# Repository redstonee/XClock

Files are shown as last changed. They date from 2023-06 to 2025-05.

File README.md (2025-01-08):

# XClock
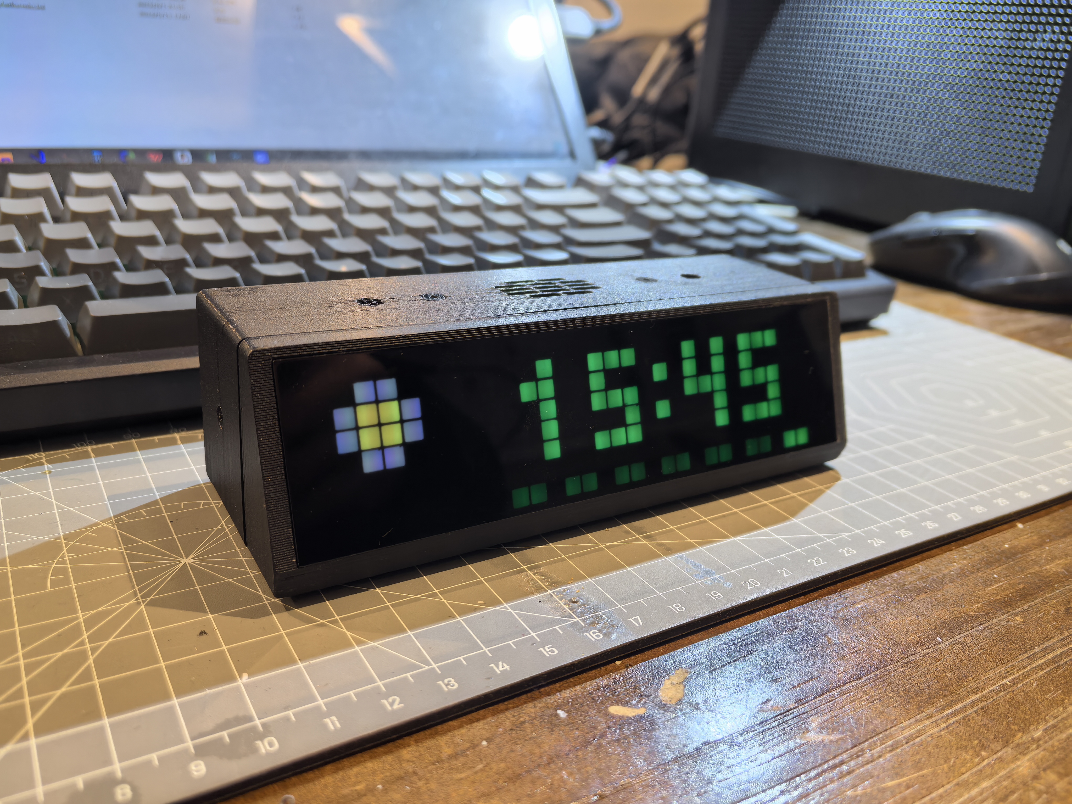
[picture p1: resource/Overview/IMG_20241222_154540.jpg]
Overview

PCB Main Board1
PCB Main Board2
PCB Display Board1
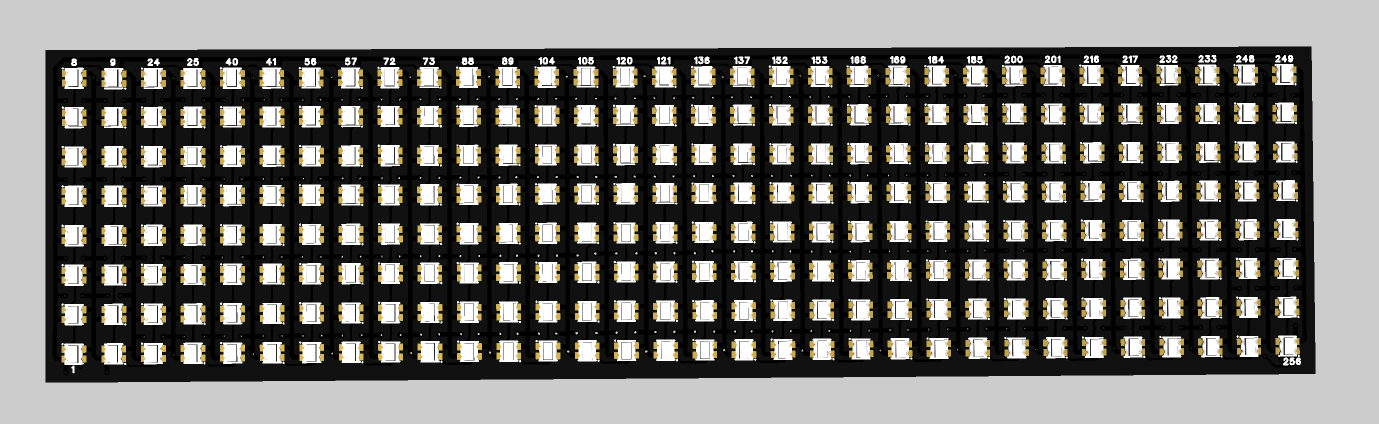
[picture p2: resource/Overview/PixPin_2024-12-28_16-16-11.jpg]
PCB Display Board2

## Background
目前网上有很多开源的点阵时钟项目，很多厉害的功能，比如可以通过小程序控制。但是大多在实用性上差那么点意思，在我的使用中最重要的一点就是需要电池供电可移动使用，我主要给我儿子写作业或者早上当闹钟使用。并且网上很多项目成品太过巨大，不够小巧。于是我萌生了自己制作一个的想法。我对点阵时钟一直有种莫名的喜爱，刚大学毕业时就打算做一个，那是还没发现有ws2812这种可以串行控制的led，现在各种硬件方案很丰富，这个项目我使用ESP32作为主控，ws2812—2020作为灯珠，能够实现非常多的功能。

## Features
* 时钟，日历，可联网显示天气
* 闹钟，可设置多个
* 秒表
* 计时器
* 音乐律动
* 显示电池电量
* 可根据环境音睡眠唤醒显示
* 可根据环境亮度自动调节显示亮度

## Usage
此时钟有3个操作按键（另外两个小按键为刷写按键），分别为左键，确认键，右键。左右键默认状态下可以切换功能，确认键可以进入每个功能的设置状态，进入设置状态之后，左右键就变为当前功能设置按键有些功能支持左右键长按操作，比如时间的加减键，功能设置状态下双击确认键可以退出设置状态。

## Hardware
硬件开源地址
[立创开源广场-XClock](https://oshwhub.com/polestar_xsx/matrixclock)

## Software
* Develop tool: VS Code + PlatformIO(vs code Extension)
* Toolchain Install：  
  1.Install VS Code  
  2.Install VS Code extension PlatformIO
  3.Git Clone soruce code  
  4.Run PlatformIO:build verify the toolchain
* 软件开发框架基于PlatformIO espressif32 arduino， PlatformIO工程中选择的开发板是esp32doit-devkit-v1。
* 使用的UI库是B站up主：创客尹白猿 开源的Dot2D库，在此表示感谢！
* 代码中使用的图片和声音资源都在resource目录下面
* 所有图片声音资源都是通过Winhex软件导出成C数组编译进ROM
* 软件支持两种图片格式：BMP，GIF。BMP用于静态图片显示，GIF用于实现动画效果。
* GIF图片使用[Pixilart](https://www.pixilart.com/ )网站编辑像素图片，导出后使用Ulead GIF Animator 5软件制作gif文件
* 声音文件使用WAV格式

## Assembly
* 外壳文件有三个，使用FreeCAD软件绘制，使用3D打印，已导出stl文件，所有文件在<resource\3DFiles\外壳>下  
  内腔.stl 前面板.stl 后壳1.stl
* 外壳使用m2x5x5平头螺丝以及配套M2x4注塑热熔铜螺母固定
* 所有连接线都是自己压线制作，连接头是2.0尺寸，当然也可以选择直接焊接不使用接插件连接
* 内置电池为两节18650，18650使用淘宝购买弹片正极端作为电极连接
* 面板淘宝定制的2mm灰色透明亚克力，尺寸38x146。亚克力后面放了一块导光膜，可以用白纸代替但是效果没那么好。
* 原理图中没有3个元件：喇叭(立创商城商品编号C969973)，光敏电阻(小于5mm)，麦克风咪头(直径9.7mm)。可根据外壳尺寸自行采购
  组装图1

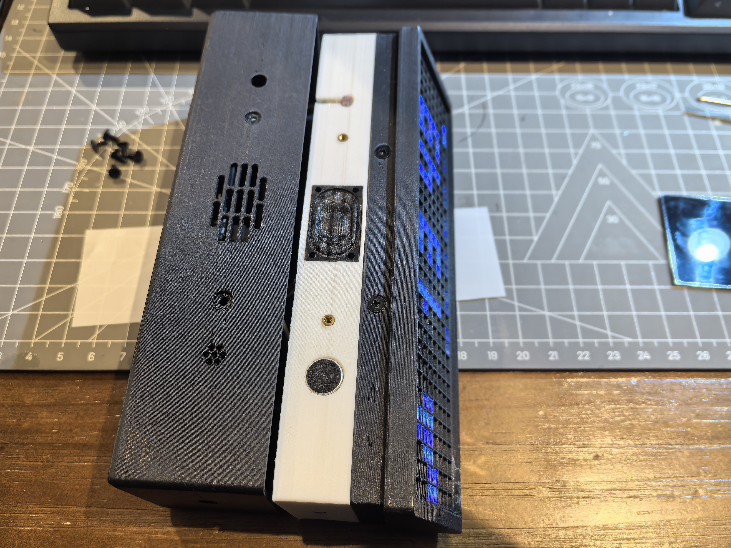
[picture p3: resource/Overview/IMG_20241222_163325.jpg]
  

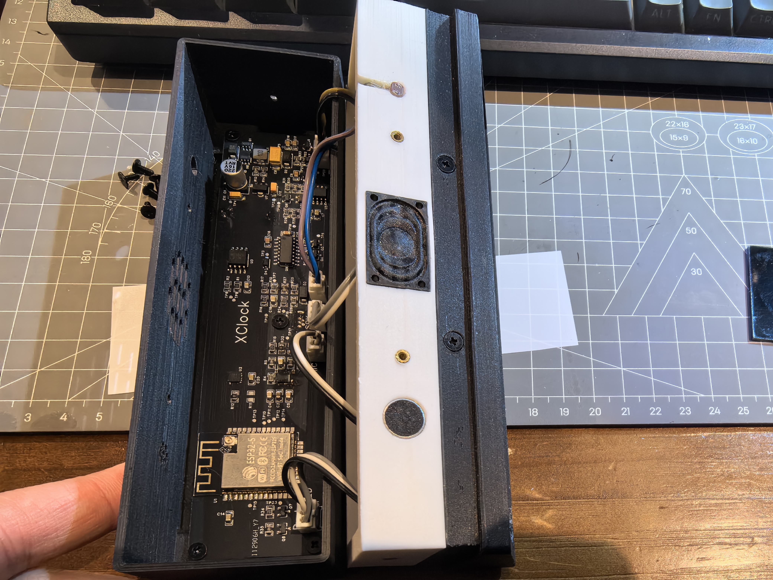
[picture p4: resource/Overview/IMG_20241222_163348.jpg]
  

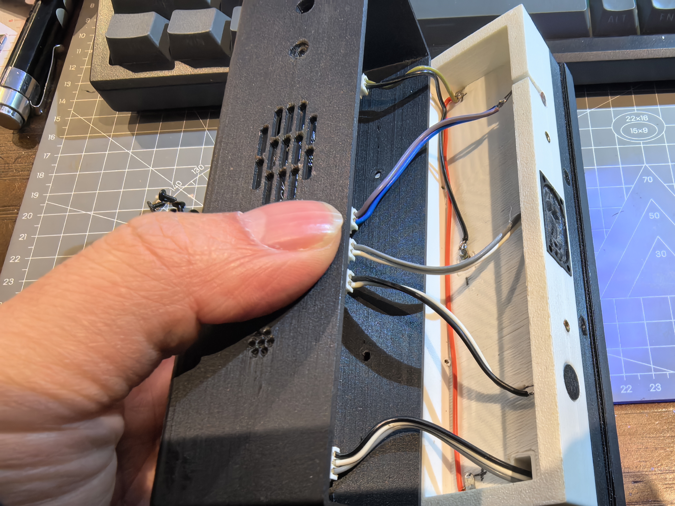
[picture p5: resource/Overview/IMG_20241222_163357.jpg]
  

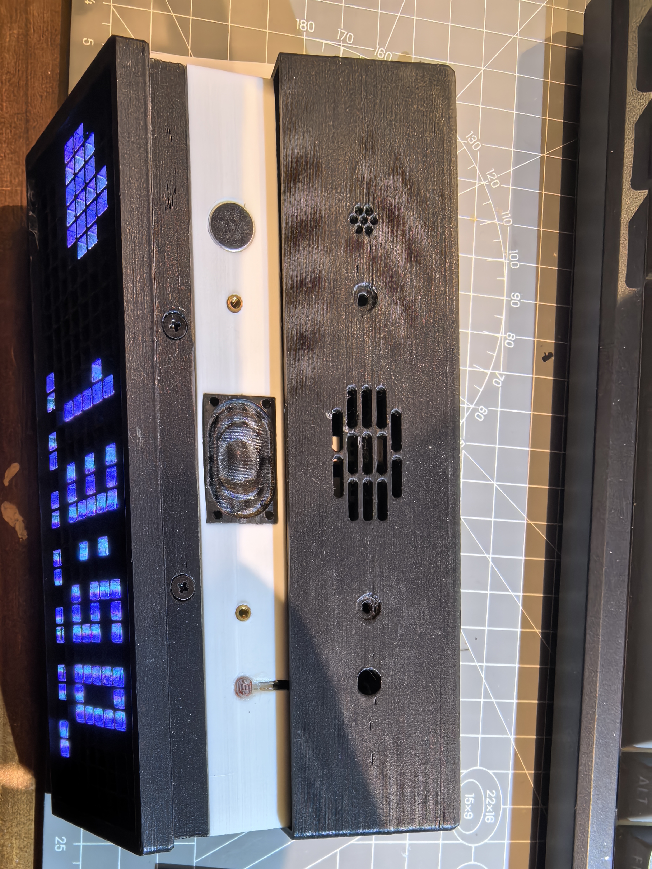
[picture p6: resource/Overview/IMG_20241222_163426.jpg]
  

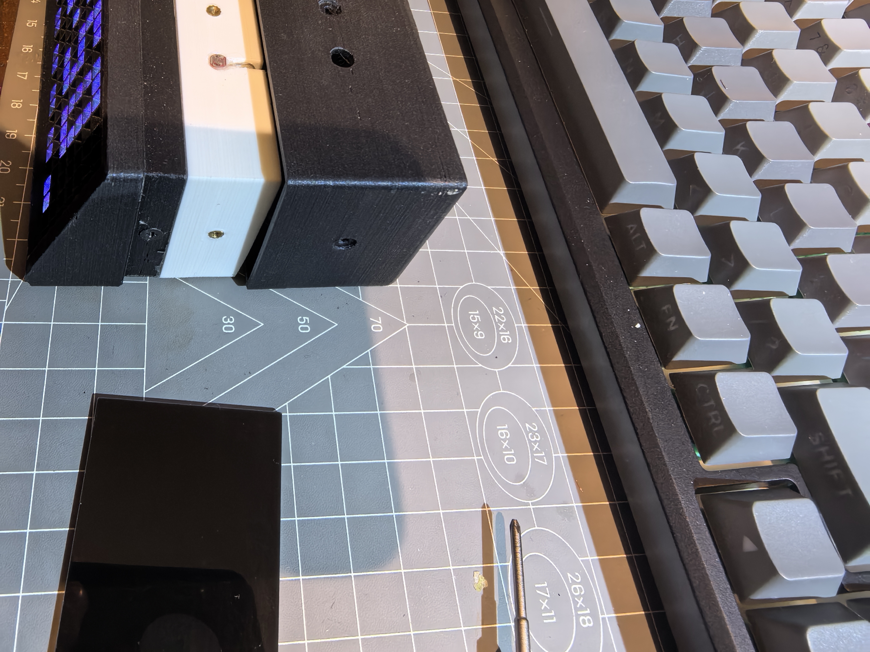
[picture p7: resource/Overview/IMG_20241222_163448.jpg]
  

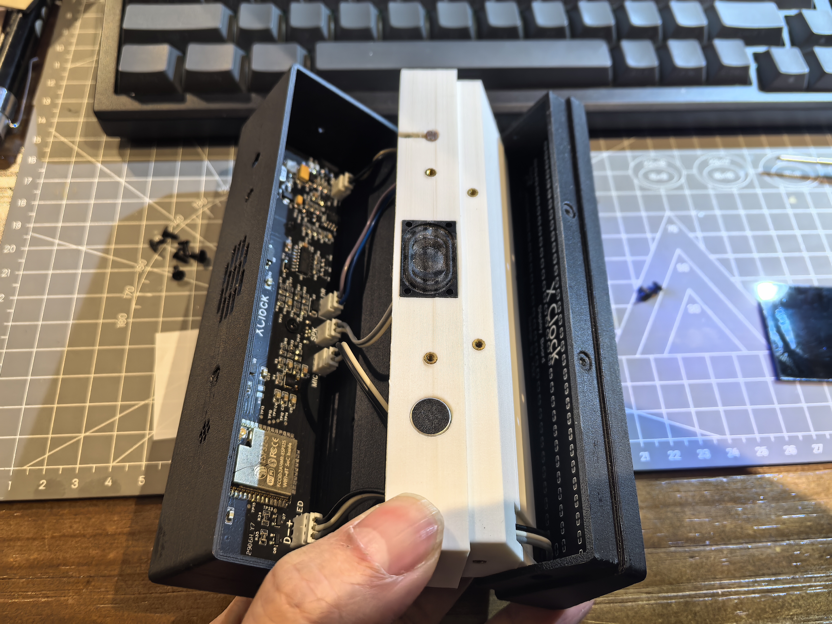
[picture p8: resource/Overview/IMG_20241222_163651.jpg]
  

  组装图1

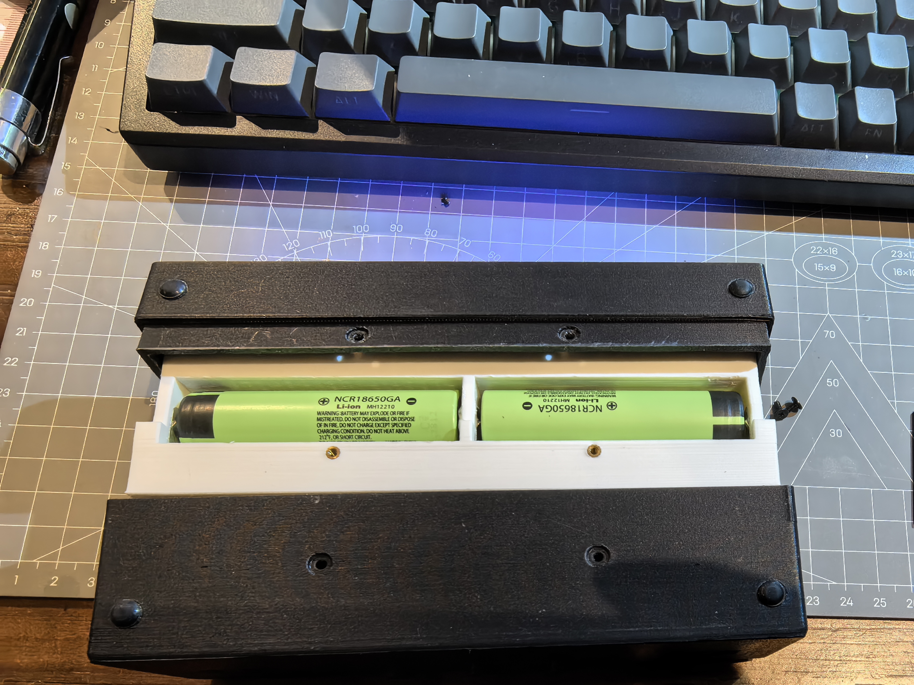
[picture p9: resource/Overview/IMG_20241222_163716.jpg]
  

  组装图1

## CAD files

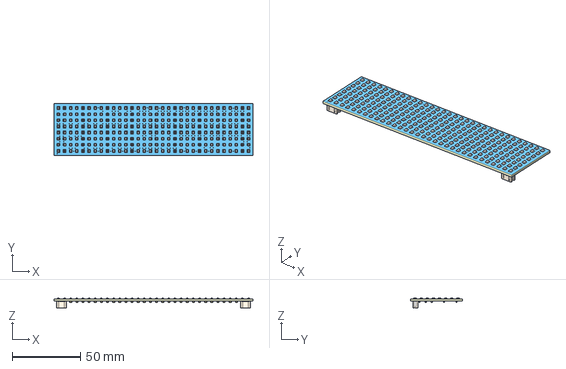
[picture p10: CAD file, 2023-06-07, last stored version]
resource/3DFiles/3D_Display_Board.step
146.0 x 38.0 x 7.54 mm

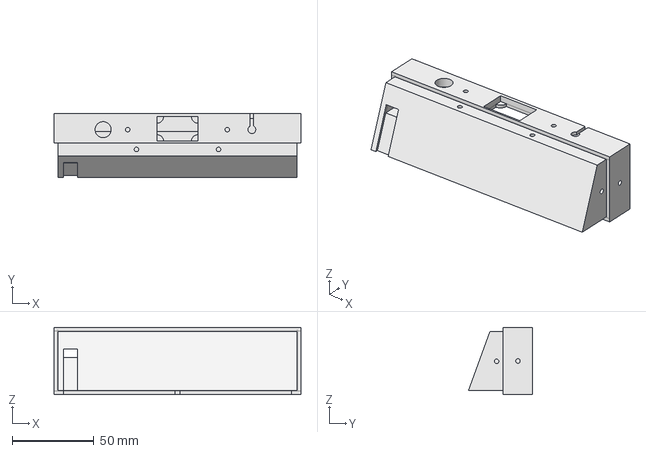
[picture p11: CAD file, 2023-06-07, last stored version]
resource/3DFiles/外壳/内腔.FCStd
150.8 x 39.2 x 40.9 mm

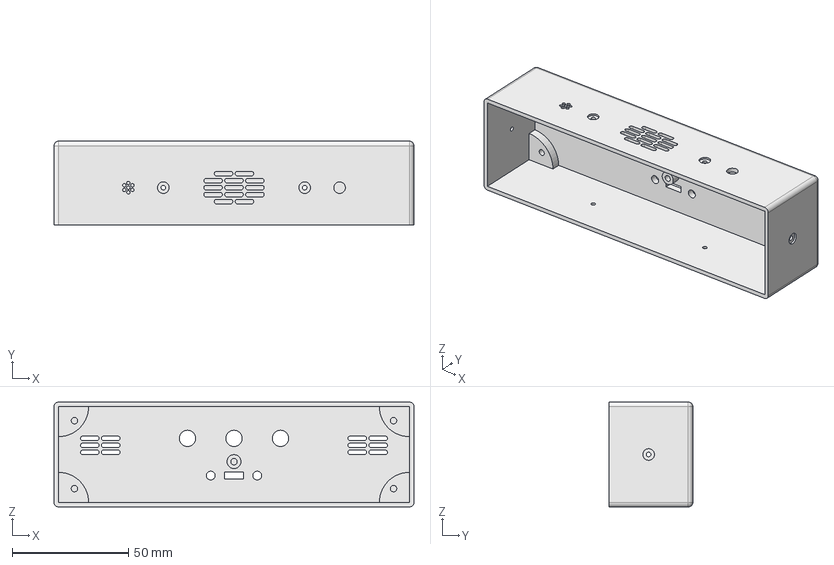
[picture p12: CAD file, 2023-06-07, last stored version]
resource/3DFiles/外壳/后壳1.FCStd
154.8 x 36.0 x 45.1 mm

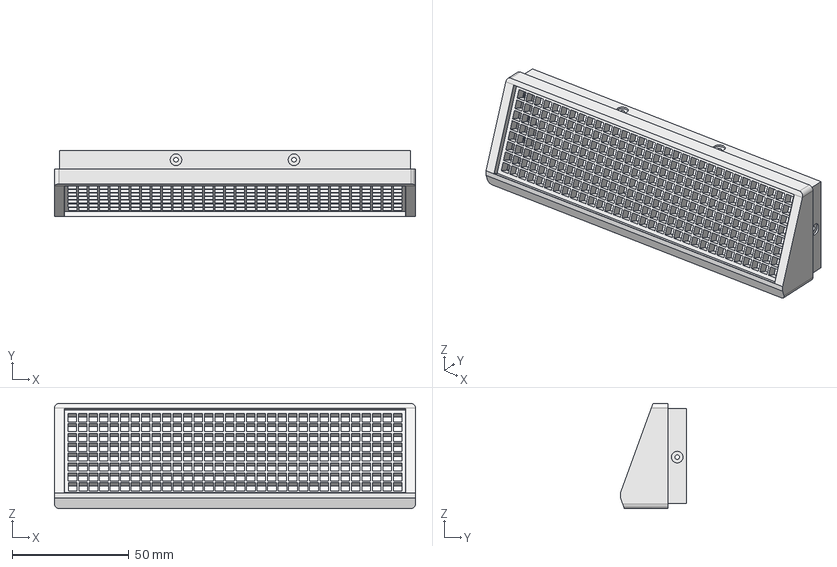
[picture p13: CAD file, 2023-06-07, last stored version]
resource/3DFiles/外壳/前面板.FCStd
154.8 x 28.3 x 45.1 mm

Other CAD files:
resource/3DFiles/外壳/内腔.stl
resource/3DFiles/外壳/前面板.stl
resource/3DFiles/外壳/后壳1.stl

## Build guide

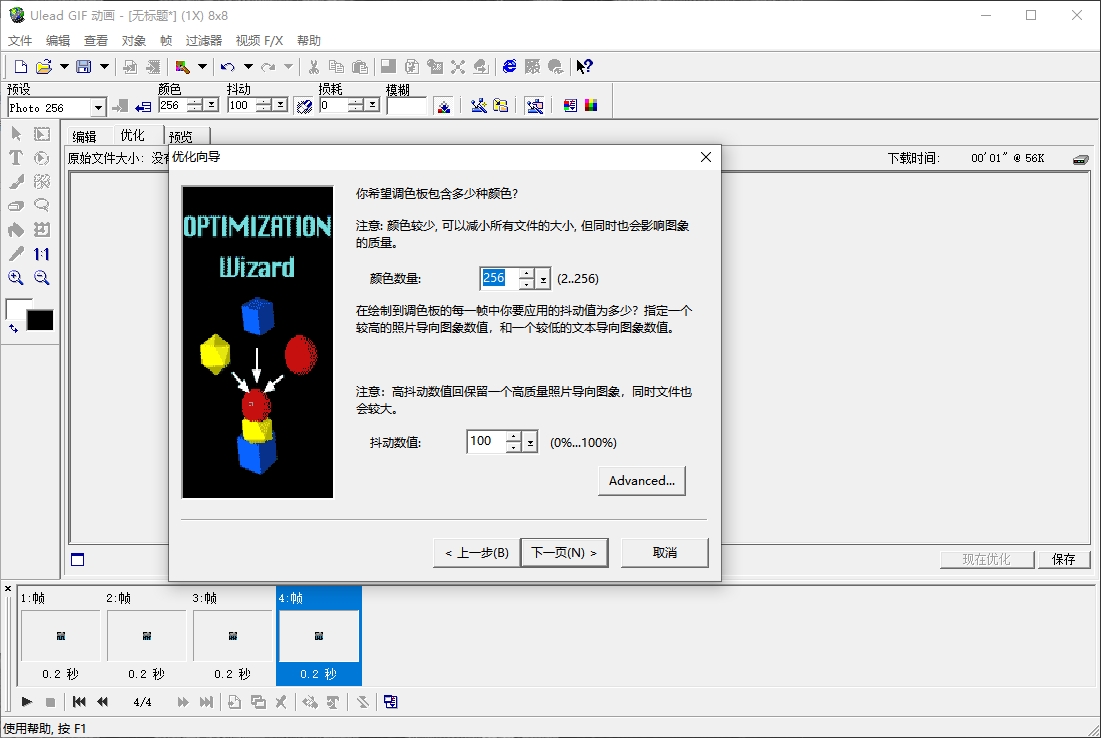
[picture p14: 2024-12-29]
resource/图标/GIF制作步骤/Step8.jpg

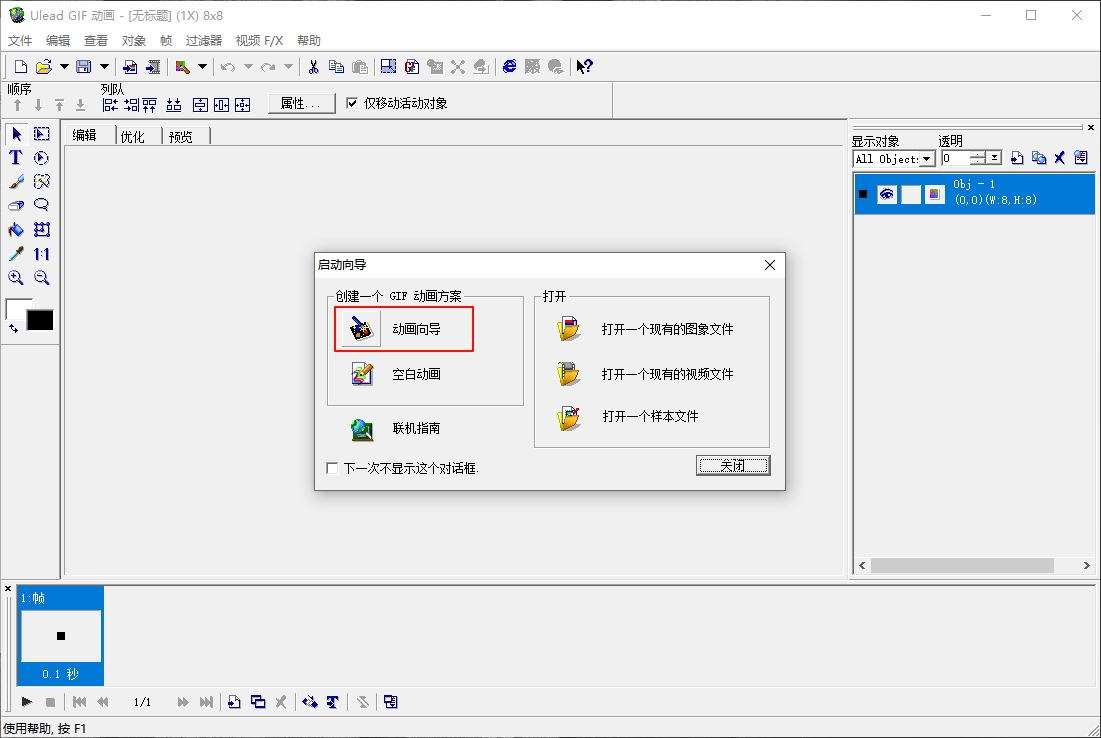
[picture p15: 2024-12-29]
resource/图标/GIF制作步骤/Step1.jpg

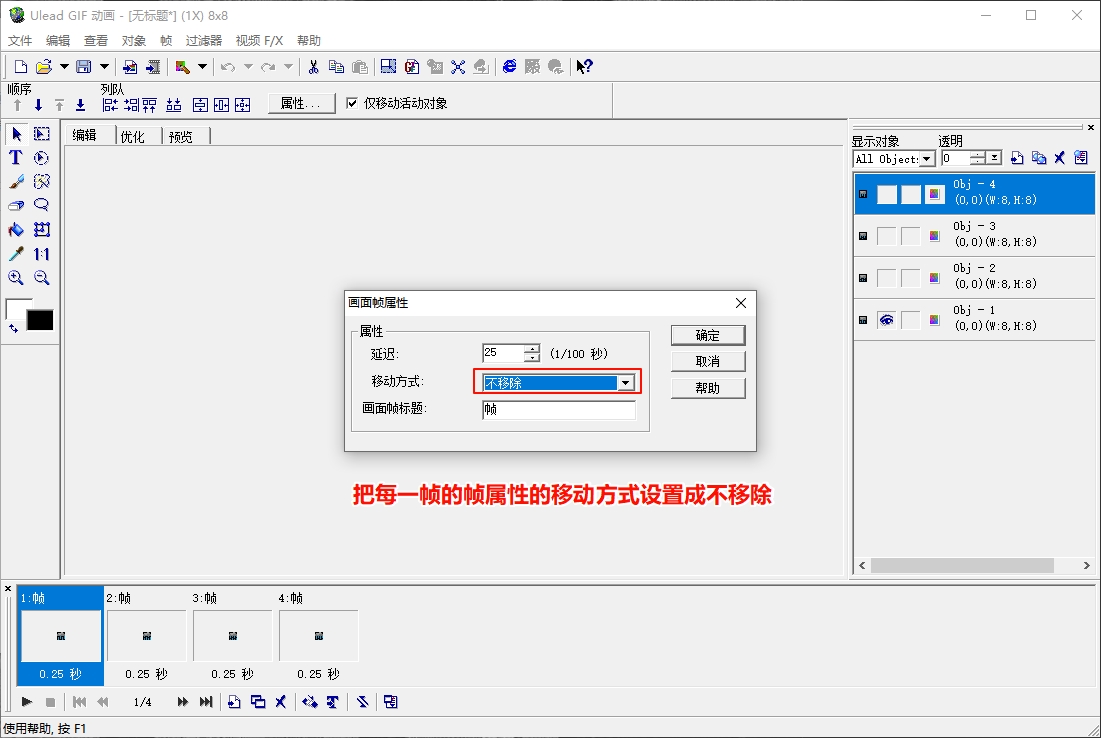
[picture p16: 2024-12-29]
resource/图标/GIF制作步骤/Step5.jpg

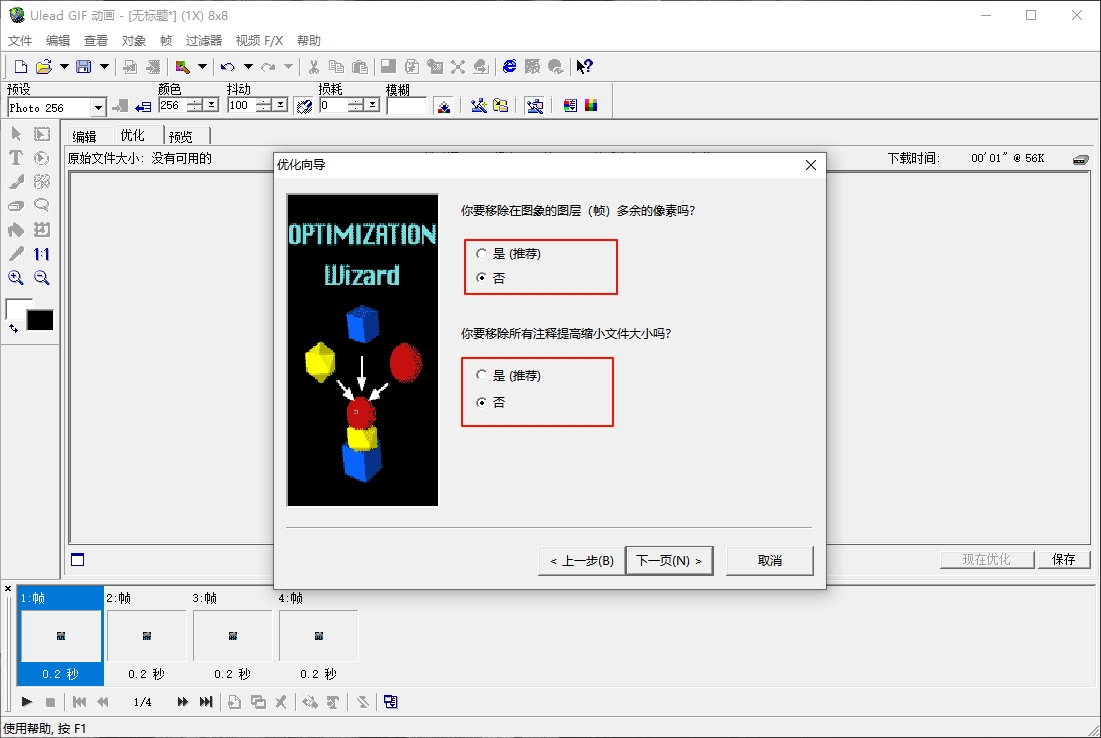
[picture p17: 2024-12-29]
resource/图标/GIF制作步骤/Step9.jpg

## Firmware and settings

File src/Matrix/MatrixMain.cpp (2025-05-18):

#include <Arduino.h>
#include "FastLED.h"
#include "Dot2D/dot2d.h"
#include "Matrix.h"
#include "MatrixMain.h"
#include "ClockScene.h"
#include "CalendarScene.h"
#include "AlarmClkScene.h"
#include "BatteryScene.h"
#include "TimerScene.h"
#include "CountDownTimer.h"
#include "FFT.h"
#include "WifiInfo.h"
#include "Sound.h"

#include "config.h"
// #include "Dot2D/math/dtMath.h"

dot2d::Director *director = nullptr;
QueueHandle_t pKeyRcvQueue = nullptr;
dot2d::Matrix *sence0 = nullptr;
dot2d::ClockScene *sence1 = nullptr;
uint8_t SceneIndex = Feature_Clock;
tstMainSts stMainSts = {Feature_Clock, Feature_None};
bool boAlarming = false;
TimerHandle_t FeatureEnterTO = nullptr;
TimerHandle_t SleepTO = nullptr;

static const char *TAG = "MatrixMain";
// 必须要实现的dot2d导演对象代理方法
class MainDelegate : public dot2d::DirectorDelegate
{

    void render()
    {
        FastLED.show();
        // 输出ESP32内存占用情况
        // Serial.printf("-----Free Heap Mem : %d [%.2f%%]-----\n",
        //         ESP.getFreeHeap(),
        //         ESP.getFreeHeap()/(double)ESP.getHeapSize()*100);
        // Serial.printf("-----Free PSRAM Mem: %d [%.2f%%]-----\n",
        //         ESP.getFreePsram(),
        //         ESP.getFreePsram()/(double)ESP.getPsramSize()*100);
    }

    size_t write(uint8_t c)
    {
        return Serial.write(c);
    }

    // 返回一个RGB对象的顺序表指针，用于初始化硬件屏幕
    void initMatrix(dot2d::DTRGB *data)
    {
        FastLED.addLeds<WS2812Controller800Khz, LED_DATA_PIN, GRB>((CRGB *)data, MATRIX_WIDTH * MATRIX_HEIGHT);
    }

    // 用于计算坐标为(x,y)的灯珠在RGB对象顺序表中的具体位置，适配不同排列方式的屏幕，在此处修改
    uint32_t dotOrder(uint16_t x, uint16_t y)
    {
        uint16_t order = x * MATRIX_HEIGHT;
        if (x % 2 == 0)
        {
            order += (MATRIX_HEIGHT - 1 - y);
        }
        else
        {
            order += y;
        }
        return order;
    }
};

dot2d::Scene *GetSceneByIdx(uint8_t idx)
{
    dot2d::Scene *TgtScene = nullptr;
    switch (idx)
    {
    case Feature_Timer:
        TgtScene = dot2d::TimerScene::create();
        break;
    case Feature_CountDown:
        TgtScene = dot2d::CountDownScene::create();
        break;
    case Feature_AlarmClk:
        TgtScene = dot2d::AlarmClkScene::create();
        break;
    case Feature_Clock:
        TgtScene = dot2d::ClockScene::create();
        break;
    case Feature_CalYear:
        TgtScene = dot2d::CalYearScene::create();
        break;
    case Feature_CalMonth:
        TgtScene = dot2d::CalMonthScene::create();
        break;
    case Feature_Battery:
        TgtScene = dot2d::BattScene::create();
        break;
    case Feature_Music:
        TgtScene = dot2d::FFT::create();
        break;
    case Feature_Wifi:
        TgtScene = dot2d::WifiInfo::create();
        break;
    default:
        TgtScene = dot2d::ClockScene::create();
        break;
    }
    return TgtScene;
}

dot2d::TransitionSlideInL *MainSceneTrans(tstKeyEvent rcvkey)
{
    dot2d::TransitionSlideInL *transition = nullptr;
    if (rcvkey.Key == enKey_Left)
    {
        if (rcvkey.Type == enKey_ShortPress)
        {
            if (stMainSts.enMainSceneIdx++ >= Feature_Last)
            {
                stMainSts.enMainSceneIdx = Feature_First;
            }
            transition = dot2d::TransitionSlideInR::create(SCENE_TRANSITION_DURATION, GetSceneByIdx(stMainSts.enMainSceneIdx));
        }
    }
    else if (rcvkey.Key == enKey_Right)
    {
        if (rcvkey.Type == enKey_ShortPress)
        {
            if (stMainSts.enMainSceneIdx-- <= Feature_First)
            {
                stMainSts.enMainSceneIdx = Feature_Last;
            }
            transition = dot2d::TransitionSlideInL::create(SCENE_TRANSITION_DURATION, GetSceneByIdx(stMainSts.enMainSceneIdx));
        }
    }
    return transition;
}

uint32_t u32ADCDataFilter(uint32_t volt)
{
    static uint32_t buffer[LIGHT_FILTER_BUFF_SIZE] = {
        0,
    };
    static uint8_t newdataindex = 0;
    static uint8_t datacnt = 0;
    uint32_t filteredvolt = 0;
    buffer[newdataindex] = volt;
    if (datacnt < LIGHT_FILTER_BUFF_SIZE)
    {
        datacnt++;
    }
    if (++newdataindex >= LIGHT_FILTER_BUFF_SIZE)
    {
        newdataindex = 0;
    }
    for (uint8_t i = 0; i < LIGHT_FILTER_BUFF_SIZE; i++)
    {
        filteredvolt += buffer[i];
    }
    filteredvolt = filteredvolt / datacnt;
    // Serial.printf("in:%d out:%d\n",volt,filteredvolt);
    return filteredvolt;
}

void vBrightessTask(void)
{
    static uint8_t u8OldBrightness = MATRIX_BRIGHTNESS_BASE;
    uint8_t u8NewBrightness = MATRIX_BRIGHTNESS_BASE;
    auto lightVoltage = analogReadMilliVolts(LIGHT_SENSOR_PIN);
    lightVoltage = u32ADCDataFilter(lightVoltage);
    if (lightVoltage > 2000)
        u8NewBrightness = 1;
    else
        u8NewBrightness = (2000 - lightVoltage) / MATRIX_LDR2LIGHT_STEP + MATRIX_BRIGHTNESS_BASE;

    if (u8OldBrightness != u8NewBrightness)
    {
        FastLED.setBrightness(u8NewBrightness);
        ESP_LOGI(TAG, "new brightness:%d\n\r", u8NewBrightness);
    }
    u8OldBrightness = u8NewBrightness;
}

void vAlarmTask(void)
{
    uint8_t AlarmNum = getAlarmClockCount();
    AlarmConfig AlarmClkTmp = {
        0,
    };
    if (AlarmNum)
    {
        for (uint8_t i = 0; i < AlarmNum; i++)
        {
            AlarmClkTmp = getAlarmClock(i);
            if (AlarmClkTmp.alarmStatus == Alarm_GoOff)
            {
                boAlarming = true;
                if (enSndID_None == enGetCurSndID())
                {
                    boReqSound(enSndID_Alarm1, 1);
                    if (Feature_Clock != stMainSts.enMainSceneIdx)
                    {
                        dot2d::TransitionSlideInL *transition = dot2d::TransitionSlideInR::create(SCENE_TRANSITION_DURATION, GetSceneByIdx(Feature_Clock));
                        if (nullptr != transition)
                        {
                            director->replaceScene(transition);
                        }
                    }
                }
                break;
            }
            else
            {
                boAlarming = false;
            }
        }
    }
}

void vAlarmClick(void)
{
    uint8_t AlarmNum = getAlarmClockCount();
    AlarmConfig AlarmClkTmp = {
        0,
    };
    if (AlarmNum)
    {
        for (uint8_t i = 0; i < AlarmNum; i++)
        {
            AlarmClkTmp = getAlarmClock(i);
            if (AlarmClkTmp.alarmStatus == Alarm_GoOff)
            {
                boAlarming = false;
                vStopSound();
                vSetAlarmClkSts(i, Alarm_Clicked);
            }
        }
    }
}

void vMatrixMain(void *param)
{
    tstKeyEvent RcvKey = {enKey_Nokey, enKey_NoAct};
    for (;;)
    {
        vTaskDelay(5);
        vAlarmTask();
        vBrightessTask();
        if (pKeyRcvQueue != nullptr)
        {
            xQueueReceive(pKeyRcvQueue, &(RcvKey), (TickType_t)0);
            if (RcvKey.Key != enKey_Nokey)
            {
                if (xTimerIsTimerActive(SleepTO))
                {
                    xTimerReset(SleepTO, 10);
                }
                if (8 == director->getRunningScene()->getPositionY())
                {
                    dot2d::MoveTo *MoveUp = dot2d::MoveTo::create(0.5, dot2d::Vec2(0, 0));
                    director->getRunningScene()->runAction(MoveUp);
                }
                xTimerReset(SleepTO, 10);
                if (boAlarming)
                {
                    vAlarmClick();
                }
                else
                {
                    if (stMainSts.enEnteredFeature == Feature_None)
                    {
                        if (RcvKey.Key != enKey_OK)
                        {
                            dot2d::TransitionSlideInL *transition = MainSceneTrans(RcvKey);
                            if (nullptr != transition)
                            {
                                director->replaceScene(transition);
                                if (Feature_Clock != stMainSts.enMainSceneIdx && Feature_Music != stMainSts.enMainSceneIdx &&
                                    Feature_Wifi != stMainSts.enMainSceneIdx && (!dot2d::boIsTimerCounterActive()) &&
                                    (!dot2d::CountDownLayer::isCountDownTimerActive()))
                                {
                                    if (nullptr != FeatureEnterTO) /*Start a timeout timer to exit the feature*/
                                    {
                                        if (xTimerIsTimerActive(FeatureEnterTO))
                                        {
                                            xTimerReset(FeatureEnterTO, 10);
                                        }
                                    }
                                }
                                else
                                {
                                    if (nullptr != FeatureEnterTO) /*Start a timeout timer to exit the feature*/
                                    {
                                        if (xTimerIsTimerActive(FeatureEnterTO))
                                        {
                                            xTimerStop(FeatureEnterTO, 10);
                                        }
                                    }
                                }
                            }
                        }
                        else
                        {
                            stMainSts.enEnteredFeature = stMainSts.enMainSceneIdx; // enter subfunctions
                            // if(Feature_Timer != stMainSts.enEnteredFeature && Feature_CountDown != stMainSts.enEnteredFeature)
                            {
                                if (nullptr != FeatureEnterTO) /*Start a timeout timer to exit the feature*/
                                {
                                    xTimerStart(FeatureEnterTO, 10);
                                }
                            }
                            dot2d::EventButton event(RcvKey.Key, (dot2d::EventButton::ButtonEventCode)RcvKey.Type);
                            auto dispatcher = dot2d::Director::getInstance()->getEventDispatcher();
                            dispatcher->dispatchEvent(&event);
                        }
                    }
                    else
                    {
                        if (RcvKey.Key == enKey_OK && RcvKey.Type == enKey_DoubleClick)
                        {
                            stMainSts.enEnteredFeature = Feature_None;
                            if (nullptr != FeatureEnterTO) /*Stop the timeout timer*/
                            {
                                if (xTimerIsTimerActive(FeatureEnterTO))
                                {
                                    xTimerStop(FeatureEnterTO, 10);
                                }
                            }
                        }
                        else
                        {
                            if (nullptr != FeatureEnterTO) /*Restart the timeout timer if any key pressed*/
                            {
                                if (xTimerIsTimerActive(FeatureEnterTO))
                                {
                                    xTimerReset(FeatureEnterTO, 10);
                                }
                            }
                            dot2d::EventButton event(RcvKey.Key, (dot2d::EventButton::ButtonEventCode)RcvKey.Type);
                            auto dispatcher = dot2d::Director::getInstance()->getEventDispatcher();
                            dispatcher->dispatchEvent(&event);
                        }
                    }
                }

                RcvKey.Key = enKey_Nokey;
                RcvKey.Type = enKey_NoAct;
            }
        }

        director->mainLoop();
    }
}

void vFeatureTOCb(TimerHandle_t xTimer)
{

    if ((Feature_Timer != stMainSts.enEnteredFeature || (!dot2d::boIsTimerCounterActive())) &&
        (Feature_CountDown != stMainSts.enEnteredFeature || (!dot2d::CountDownLayer::isCountDownTimerActive())) &&
        Feature_Music != stMainSts.enEnteredFeature && Feature_Wifi != stMainSts.enMainSceneIdx)
    {
        stMainSts.enEnteredFeature = Feature_None;
        stMainSts.enMainSceneIdx = Feature_Clock;
        dot2d::TransitionSlideInL *transition = dot2d::TransitionSlideInR::create(SCENE_TRANSITION_DURATION, GetSceneByIdx(Feature_Clock));
        if (nullptr != transition)
        {
            director->replaceScene(transition);
        }
    }
    else
    {
        stMainSts.enEnteredFeature = Feature_None;
    }
}

void vOffSeqFinishCb()
{
    ClearWakeupRequest(true);
}

void vSleepTOCb(TimerHandle_t xTimer)
{
    ESP_LOGW(TAG, "Sleep timeout");
    if (stMainSts.enEnteredFeature == Feature_None && stMainSts.enMainSceneIdx != Feature_CountDown &&
        stMainSts.enMainSceneIdx != Feature_Timer && stMainSts.enMainSceneIdx != Feature_Music &&
        Feature_Wifi != stMainSts.enMainSceneIdx)
    {
        dot2d::MoveTo *MoveOff = dot2d::MoveTo::create(0.5, dot2d::Vec2(0, 8));
        dot2d::Sequence *OffSeq = dot2d::Sequence::createWithTwoActions(MoveOff, dot2d::CallFunc::create(vOffSeqFinishCb));
        director->getRunningScene()->runAction(OffSeq);
    }
    else
    {
        xTimerReset(SleepTO, 10);
    }
}

void vResetSleepTimer()
{
    if (xTimerIsTimerActive(SleepTO))
    {
        xTimerReset(SleepTO, 10);
    }
}

void vMatrixInit(QueueHandle_t rcvQ)
{
    // 设置WS2812屏幕亮度
    FastLED.setBrightness(MATRIX_BRIGHTNESS_BASE);
    pKeyRcvQueue = rcvQ;
    uint8_t sceneindex = Feature_Clock;
    stMainSts.enMainSceneIdx = Feature_Clock;
    stMainSts.enEnteredFeature = Feature_None;
    //----------------Init scene list------------------------
    // sence0 = dot2d::Matrix::create();
    // Serial.printf("SceneMtri %x\n",&sence0);
    // sence1 = dot2d::ClockScene::create();
    // Serial.printf("SceneClk %x\n",&sence1);
    //----------------初始化Dot2d引擎及渲染画布----------------
    RequestWakeup(true);
    director = dot2d::Director::getInstance();            // 获取导演对象
    director->setDelegate(new MainDelegate());            // 设置导演代理
    director->setFramesPerSecond(30);                     // 设置帧速率
    director->initDotCanvas(MATRIX_WIDTH, MATRIX_HEIGHT); // 初始化导演画布
    // director->runWithScene(dot2d::Matrix::create());
    director->runWithScene(dot2d::ClockScene::create());
    FeatureEnterTO = xTimerCreate(/* Just a text name, not used by the RTOS
                                  kernel. */
                                  "FeatureTimer",
                                  /* The timer period in ticks, must be
                                  greater than 0. */
                                  FeatureTimeout,
                                  /* The timers will auto-reload themselves
                                  when they expire. */
                                  pdFALSE,
                                  /* The ID is used to store a count of the
                                  number of times the timer has expired, which
                                  is initialised to 0. */
                                  (void *)0,
                                  /* Each timer calls the same callback when
                                  it expires. */
                                  vFeatureTOCb);
    SleepTO = xTimerCreate(/* Just a text name, not used by the RTOS
                           kernel. */
                           "FeatureTimer",
                           /* The timer period in ticks, must be
                           greater than 0. */
                           SleepTimeout,
                           /* The timers will auto-reload themselves
                           when they expire. */
                           pdFALSE,
                           /* The ID is used to store a count of the
                           number of times the timer has expired, which
                           is initialised to 0. */
                           (void *)0,
                           /* Each timer calls the same callback when
                           it expires. */
                           vSleepTOCb);
    xTimerStart(SleepTO, 10);
    xTaskCreatePinnedToCore(
        vMatrixMain,        // Function that should be called
        "Matrix main task", // Name of the task (for debugging)
        4000,               // Stack size (bytes)
        NULL,               // Parameter to pass
        4,                  // Task priority
        NULL,               // Task handle
        1                   // core, fastled seems must pin to core 1 and wifi pin to core0, otherwise the fastled will have flicker
    );
}

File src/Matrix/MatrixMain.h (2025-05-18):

#ifndef __MATRIX_MAIN__
#define __MATRIX_MAIN__
#include "ClockKey.h"
// LED矩阵宽
#define MATRIX_WIDTH (32)
// LED矩阵高
#define MATRIX_HEIGHT (8)
// 屏幕最小亮度
#define MATRIX_BRIGHTNESS_BASE (1)
// 光敏电阻转换亮度的步长
#define MATRIX_LDR2LIGHT_STEP (100)
// #define MATRIX_LDR2LIGHT_STEP (250)
// 换场时间
#define SCENE_TRANSITION_DURATION (0.5f)

#define FeatureTimeout (portTICK_PERIOD_MS * 1000 * 30)

#define SleepTimeout (portTICK_PERIOD_MS * 1000 * 60 * 3)

typedef enum
{
    Feature_None = 0,
    Feature_First,
    Feature_Timer = Feature_First,
    Feature_CountDown,
    Feature_AlarmClk,
    Feature_Clock,
    Feature_CalYear,
    Feature_CalMonth,
    Feature_Battery,
    Feature_Music,
    Feature_Wifi,
    Feature_Last = Feature_Wifi,
} tenFeatureID;

typedef struct
{
    uint8_t enMainSceneIdx;
    uint8_t enEnteredFeature;
} tstMainSts;

void vMatrixInit(QueueHandle_t);
void vResetSleepTimer();
#endif

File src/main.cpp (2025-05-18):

#include <Arduino.h>
#include <arduinoFFT.h>
#include <WiFi.h>
#include "config.h"
#include "FastLED.h"
#include "Dot2D/dot2d.h"
#include "Matrix/MatrixMain.h"
#include "ClockKey.h"
#include "Network.h"
#include "SD3078.hpp"
#include "AlarmClk.h"
#include "Sound.h"
#include "BattMon.h"
#include "shitTime.h"

QueueHandle_t KeyQueue = nullptr;
static SD3078 RTC(RTC_SDA_PIN, RTC_SCL_PIN, RTC_ADDR);

static const char *TAG = "Main";

uint8_t i8SleepReqCnt = 0;
uint8_t i8SleepReqHMICnt = 0;
static double realComponent[64];
static double imagComponent[64];
arduinoFFT *fft = new arduinoFFT(realComponent, imagComponent, 64, 8000);

void vCreateKeyQueue(void)
{
    KeyQueue = xQueueCreate(
        /* The number of items the queue can hold. */
        5,
        /* Size of each item is big enough to hold the
        whole structure. */
        sizeof(tstKeyEvent));
}

void RequestWakeup(bool boHMIDis)
{
    if (boHMIDis)
        i8SleepReqHMICnt++;
    else
        i8SleepReqCnt++;
}

inline bool isWakeupNeeded(bool boHMIDis)
{
    return boHMIDis ? (i8SleepReqHMICnt > 0) : (i8SleepReqCnt > 0);
}

void ClearWakeupRequest(bool boHMIDis)
{
    if (boHMIDis)
    {
        if (i8SleepReqHMICnt)
            i8SleepReqHMICnt--;
    }
    else
    {
        if (i8SleepReqCnt)
            i8SleepReqCnt--;
    }
}

void vCheckAlarms(tm currentTime)
{
    uint8_t AlarmNum = getAlarmClockCount();
    AlarmConfig AlarmClkTmp = {
        0,
    };
    if (AlarmNum)
    {
        for (uint8_t i = 0; i < AlarmNum; i++)
        {
            AlarmClkTmp = getAlarmClock(i);
            if (AlarmClkTmp.isActive)
            {
                if ((AlarmClkTmp.alarmStatus == Alarm_Idle))
                {
                    if ((AlarmClkTmp.hour == currentTime.tm_hour) && (AlarmClkTmp.minute == currentTime.tm_min) &&
                        (AlarmClkTmp.week & (1 << (currentTime.tm_wday == 0 ? 6 : (currentTime.tm_wday - 1)))))
                    {
                        ESP_LOGI(TAG, "Alarming!\n\r");
                        vSetAlarmClkSts(i, Alarm_GoOff);
                        RequestWakeup(true);
                    }
                }
                else if (AlarmClkTmp.alarmStatus == Alarm_Clicked || AlarmClkTmp.alarmStatus == Alarm_GoOff)
                {
                    if ((AlarmClkTmp.hour != currentTime.tm_hour) || (AlarmClkTmp.minute != currentTime.tm_min) ||
                        ((AlarmClkTmp.week & (1 << (currentTime.tm_wday == 0 ? 6 : (currentTime.tm_wday - 1)))) == 0))
                    {
                        ESP_LOGI(TAG, "Alarming disabled!\n\r");
                        vSetAlarmClkSts(i, Alarm_Idle);
                        ClearWakeupRequest(true);
                    }
                }
            }
        }
    }
}

void goToSleep(bool enableTimerWake = true)
{
    ESP_LOGI(TAG, "Go to sleep\n\r");
    digitalWrite(MIC_EN_PIN, LOW);
    digitalWrite(LED_EN_PIN, LOW);
    esp_sleep_enable_ext0_wakeup(static_cast<gpio_num_t>(BUTTON_OK_PIN), 0);
    if (enableTimerWake)
        esp_sleep_enable_timer_wakeup(SLEEP_TIME);
    esp_deep_sleep_start();
}

bool isNoisy()
{
    for (int i = 0; i < 64; i++)
    {
        realComponent[i] = analogReadMilliVolts(MIC_SIG_PIN);
        imagComponent[i] = 0;
    }
    fft->DCRemoval();
    fft->Windowing(FFT_WIN_TYP_HAMMING, FFT_FORWARD);
    fft->Compute(FFT_FORWARD);
    fft->ComplexToMagnitude();
    double sum = 0;
    for (int i = 0; i < 64; i++) /*计算每个频率段的中值和最大值*/
    {
        sum += realComponent[i];
    }
    if (sum > NOISE_THRESH)
    {
        ESP_LOGD(TAG, "nosiy %g\n\r", sum);
        return true;
    }
    ESP_LOGD(TAG, "%g\n\r", sum);
    return false;
}

void setup()
{
    BattMon::begin();
    delay(100);
    if (BattMon::getBatteryLevel() < 10)
    {
        ESP_LOGE(TAG, "Battery level is low\n\r");
        goToSleep(false);
    }

    if (!RTC.begin())
    {
        ESP_LOGE(TAG, "Failed to initialize RTC\n\r");
        goToSleep();
    }
    ESP_LOGI(TAG, "RTC initialized\n\r");

    if (!vSoundInit())
    {
        ESP_LOGE(TAG, "Sound Init failed\n\r");
        goToSleep();
    }
    ESP_LOGI(TAG, "Sound Init success\n\r");

    boInitAlarmClkList();

    setenv("TZ", "CST-8", 1);
    tzset();

    // Set the system time to RTC time
    tm currentTime;
    if (!RTC.getTime(&currentTime))
    {
        ESP_LOGE(TAG, "Failed to read RTC time\n\r");
        goToSleep();
    }
    setSystemTime(currentTime);

    vCheckAlarms(currentTime);

    ESP_LOGD(TAG, "Fuck Me");

    pinMode(MIC_EN_PIN, OUTPUT);
    digitalWrite(MIC_EN_PIN, HIGH);
    analogSetPinAttenuation(MIC_SIG_PIN, ADC_6db);
    
    // Don't wake up by noise when battery level is not really high
    bool noisy = false;
    if (BattMon::getBatteryLevel() > 50)
    {
        delay(50); // delay for ADC stable
        noisy = isNoisy();
    }

    if (noisy || isWakeupNeeded(true) || ESP_SLEEP_WAKEUP_EXT0 == esp_sleep_get_wakeup_cause())
    {
        vCreateKeyQueue();
        static ClockKey keyHandler;
        keyHandler.SetSendQueue(KeyQueue);
        keyHandler.Start();
        pinMode(LED_EN_PIN, OUTPUT);
        digitalWrite(LED_EN_PIN, HIGH);

        vMatrixInit(KeyQueue);
    }

    if (!(isWakeupNeeded(true) || isWakeupNeeded(false)))
    {
        goToSleep();
    }

    Network::begin();
}

void loop()
{
    delay(5000);

    if (BattMon::getBatteryLevel() < 10)
    {
        ESP_LOGE(TAG, "Battery level is low\n\r");
        goToSleep(false);
    }

    tm currentTime;
    getLocalTime(&currentTime);
    vCheckAlarms(currentTime);
    RTC.setTime(currentTime);

    if (!(isWakeupNeeded(true) || isWakeupNeeded(false)))
    {
        goToSleep();
    }

    if ((BattMon::getBatteryLevel() > 50) && isNoisy())
    {
        vResetSleepTimer();
    }
}

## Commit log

2023-03-04 Add sound feature，add gif,bmp decoder
2023-03-30 Add transition action and fix gif memory leak bug
    [GifClass.cpp, dtActionEase.cpp]
2023-04-06 fix a gif reset bug,add some features
    [BmpClass.cpp, ClockKey.cpp]
2023-05-04 Add feature timeout, add alarm clock switch icon
2023-05-05 Add switch animation
2023-05-08 Add alarm clock switch animation
2023-05-09 Add timer scene
2023-05-10 finish the timer feature
2023-05-12 Add count down timer
2023-06-07 Add resource files and update some code
    [3D_Display_Board.step, 内腔.FCStd, 前面板.FCStd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]
2024-12-24 add pictures and stl files
    [内腔.stl, 前面板.stl, 后壳1.stl]
2025-01-08 Update md，add address of the firmware
2025-04-27 Remove 3D models from sources
    [3D_Display_Board.step, 内腔.FCStd, 内腔.stl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]
2025-04-28 Use ESP32 logger instead of Serial.print
2025-05-09 Fix RTC time getting and battery level measuring
    [BattMon.cpp, main.cpp]
2025-05-09 Tick keys with OS Timer, move some light sensor const vals into the config file
2025-05-15 Make countdown timer smarter
2025-05-18 Don't wake up by noise when battery level is below 50
    [MatrixMain.cpp, MatrixMain.h, main.cpp]
